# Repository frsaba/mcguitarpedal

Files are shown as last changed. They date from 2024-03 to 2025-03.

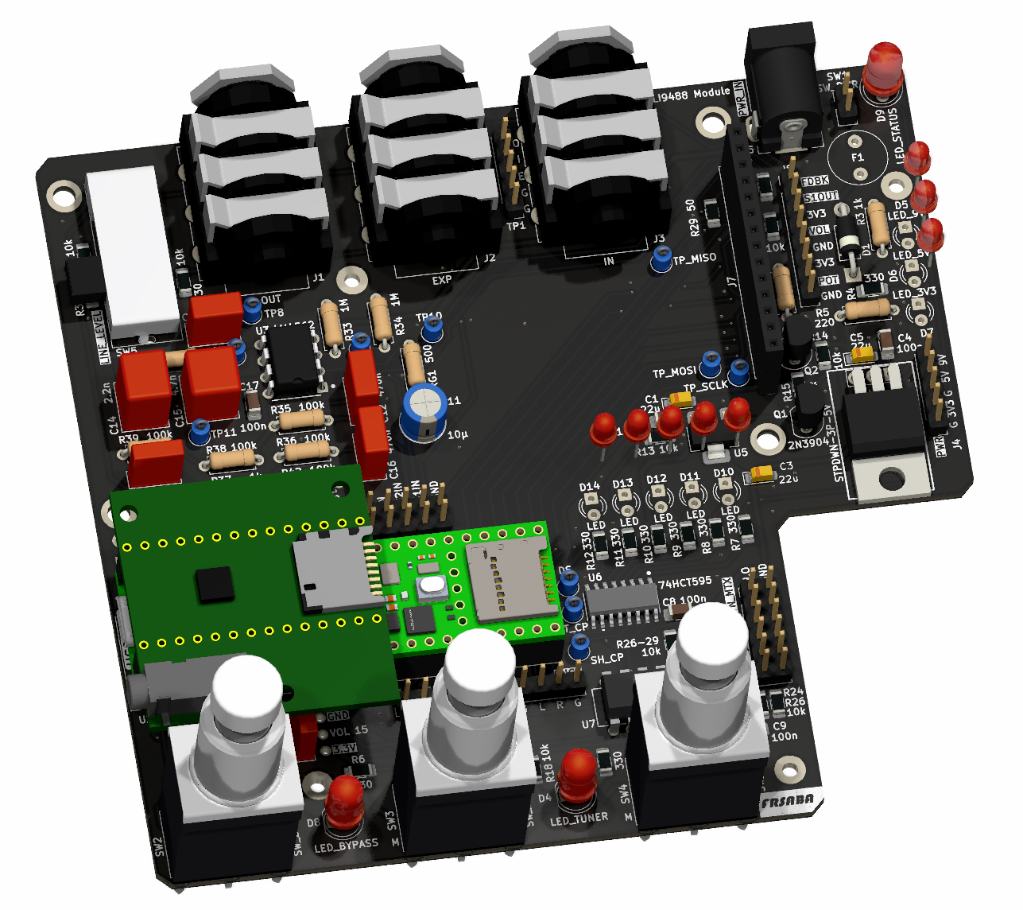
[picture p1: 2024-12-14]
pcb/pcb_3d.png

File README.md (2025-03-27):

# Teensy 4.1 Guitar Effects Pedal


#### Custom dual-layer PCB design:
- LM4562 based preamplifier stage with adjustable gain (1-20x) and 3-way attenuation switch for line-level compatibility
- 8+2+1 programmable buttons (up to 8 pushbuttons, 2 footswitches, 1 true bypass switch)
- 3 potentiometers (preamp gain + 2 programmable)
- 3 encoders (3 headers, but 2 are in use for now)
- 8 programmable LEDs
- 9V barrel jack input or USB power

[PCB design, front side](https://github.com/user-attachments/files/19494445/pcb_front.pdf)

[PCB design, back side](https://github.com/user-attachments/files/19494519/pcb_back.pdf)

pcb_3d

20241130_164746_cropped

## Hardware
- [Teensy 4.1](https://www.pjrc.com/store/teensy41.html)
- [Teensy Audio Adaptor board](https://www.pjrc.com/store/teensy3_audio.html)
- ILI9488 LCD panel (backlight brightness adjustable with PWM)

## Software


- C++ with PlatformIO
- [Teensy Audio Library](https://github.com/PaulStoffregen/Audio)
- UI made with [LVGL](https://lvgl.io)
- 5 implemented effects (more to come):
  - Chorus
  - Flanger
  - Tremolo
  - Delay
  - Reverb

Each effect can be separately toggled on/off and mixed with the dry/wet parameter. The effect parameters can be adjusted to tune the sound.

#### Misc. features
- Tuner mode
- Adjustable LED and display brightness
- Bypass switch
- Signal level feedback LED
- USB audio device for recording
- Headphone monitor out via Audio Board

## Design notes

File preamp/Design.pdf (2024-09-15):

## Filter Wizard

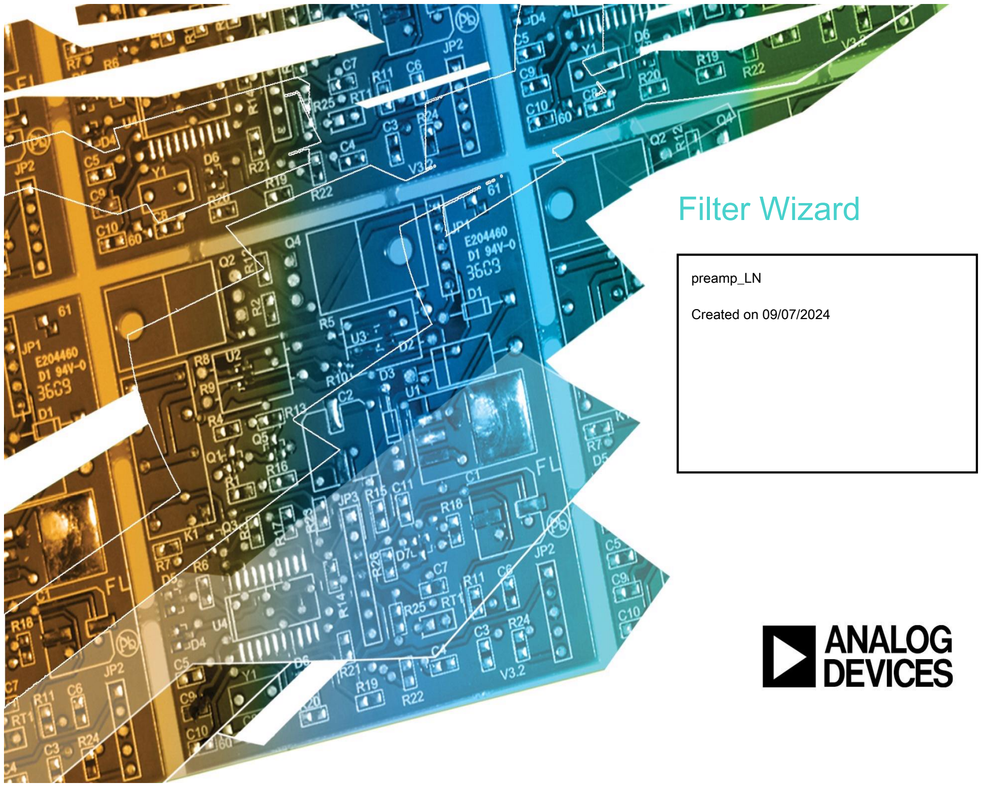
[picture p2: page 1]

preamp_LN

Created on 09/07/2024

## Filter Wizard Design Report

Filter Requirements for Low-Pass, 2nd order Butterworth Specifications: Optimize: Noise; +Vs: 9; -Vs: 0
Gain: 0 dB
Passband: -3dB at 30kHz
Stopband: -20dB at 100kHz
Component Tolerances: Capacitor = 10%; Resistor = 5%; Inductor = 5%; Op Amp GBW = 20% BOM: refer to BOM.csv file

Magnitude(dB)

Magnitude(Volts per Volt)

Phase(degrees)

Phase(radians)

Group Delay

Phase Delay

Step Response

Input Impedance Magnitude

Input Impedance Phase

Noise

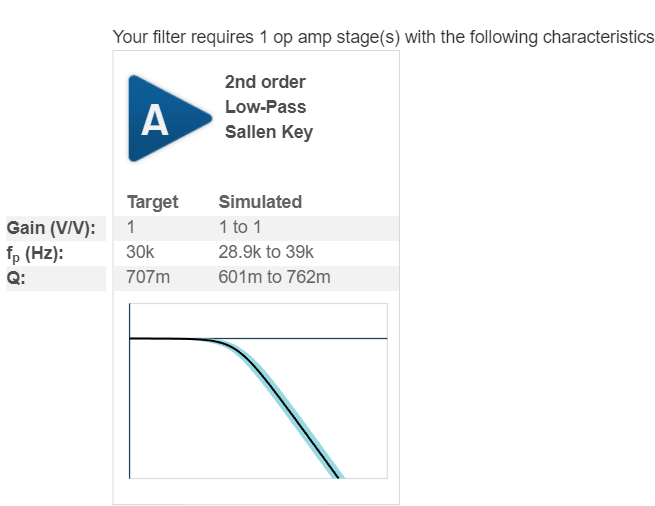
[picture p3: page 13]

Stages

Circuit

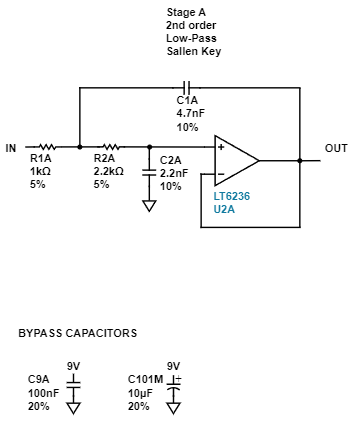
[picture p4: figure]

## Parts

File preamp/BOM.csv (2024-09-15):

Quantity | Reference Designator | Model
1 | R1A | 1.5k ohm, 0603, 5%
1 | R2A | 3.3k ohm, 0603, 5%
3 | R4A, R5M, JP2 | 0 ohm, 0603
1 | C1A | 4.7nF, 0603, C0G, 10%
1 | C2A | 2.2nF, 0603, C0G, 10%
1 | C9A | 100nF, 0603, X7R, 20%
1 | C101M | 10µF, 6032, tantalum, 20%
1 | U1A | ADA4898-1, SOIC EP
4 | J1M, J2M, J3M, J4M | 67996-206HLF, 2x3 0.1" header
3 | J2M, J3M, J4M | 65474-010LF, 0.1" jumper
1 | J1A | BCS-103-L-D-TE, 2x3 0.1" socket
2 | J5M, J6M | 142-0701-851, SMA Jack, board edge female
3 | +VS, -VS, GND | 68000-101HLF, Test pin

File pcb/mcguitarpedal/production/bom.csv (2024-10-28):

Designator | Footprint | Quantity | Value | LCSC Part #
C1, C3, C5, C6 | CP_EIA-3216-18_Kemet-A_Pad1.58x1.35mm_HandSolder | 4 | 22u
C10, C12, C16 | C_Rect_L7.2mm_W3.5mm_P5.00mm_FKS2_FKP2_MKS2_MKP2 | 3 | 470n
C11 | CP_Radial_D6.3mm_P2.50mm | 1 | 10µ
C13 | C_Rect_L7.2mm_W2.5mm_P5.00mm_FKS2_FKP2_MKS2_MKP2 | 1 | 220n
C14 | C_Rect_L7.5mm_W6.5mm_P5.00mm | 1 | 2.2n
C15 | C_Rect_L7.2mm_W7.2mm_P5.00mm_FKS2_FKP2_MKS2_MKP2 | 1 | 4.7n
C17, C2, C4, C8, C9 | 1206 | 5 | 100n
C7 | C_Rect_L7.2mm_W2.5mm_P5.00mm_FKS2_FKP2_MKS2_MKP2 | 1 | 100n
D1, D2, D3 | D_DO-41_SOD81_P10.16mm_Horizontal | 3 | D_Schottky
D10, D11, D12, D13, D14 | LED_D3.0mm | 5 | LED
D4 | LED_D5.0mm | 1 | LED_TUNER
D5 | LED_D3.0mm | 1 | LED_9V
D6 | LED_D3.0mm | 1 | LED_5V
D7 | LED_D3.0mm | 1 | LED_3V3
D8 | LED_D5.0mm | 1 | LED_BYPASS
D9 | LED_D5.0mm | 1 | LED_STATUS
F1 | Fuse_Littelfuse_395Series | 1 | Fuse 1A
J1 | Jack_6.35mm_Neutrik_NMJ6HCD2_Horizontal_3D_MODEL | 1 | OUT
J10 | Encoder_headers | 1 | ENC2
J11 | Encoder_headers | 1 | ENC3
J12 | PinHeader_2x06_P2.54mm_Vertical | 1 | BTN_MTX
J2 | Jack_6.35mm_Neutrik_NMJ6HCD2_Horizontal_3D_MODEL | 1 | EXP
J3 | Jack_6.35mm_Neutrik_NMJ6HCD2_Horizontal_3D_MODEL | 1 | IN
J4 | PinHeader_1x05_P2.54mm_Vertical | 1 | PWR
J5 | BarrelJack_Kycon_KLDX-0202-xC_Horizontal | 1 | PWR_IN
J6 | PREAMP_HEADERS | 1 | PREAMP_HEADERS
J7 | ILI9488 | 1 | ILI9488 Module
J8 | POTS_HEADER | 1 | POT_HP_VOLUME_10k
J9 | Encoder_headers | 1 | ENC1
Q1 | TO-92_Inline | 1 | 2N3904
Q2 | TO-92_Inline | 1 | BC416
R1, RG1 | R_Axial_DIN0207_L6.3mm_D2.5mm_P7.62mm_Horizontal | 2 | 500
R10, R11, R12, R16, R2, R4, R6, R7, R8, R9 | 1206 | 10 | 330
R13, R14, R15, R18, R19, R20, R21, R22, R23, R24, R25, R26, R30, R31, R32 | 1206 | 15 | 10k
R17 | R_Axial_DIN0207_L6.3mm_D2.5mm_P7.62mm_Horizontal | 1 | 100
R27, R28, R29 | 1206 | 3 | 50
R3, R37 | R_Axial_DIN0207_L6.3mm_D2.5mm_P7.62mm_Horizontal | 2 | 1k
R33, R34 | R_Axial_DIN0207_L6.3mm_D2.5mm_P7.62mm_Horizontal | 2 | 1M
R35, R36, R38, R39, R41, R42 | R_Axial_DIN0207_L6.3mm_D2.5mm_P7.62mm_Horizontal | 6 | 100k
R40 | R_Axial_DIN0207_L6.3mm_D2.5mm_P7.62mm_Horizontal | 1 | 2.2k
R5 | R_Axial_DIN0207_L6.3mm_D2.5mm_P7.62mm_Horizontal | 1 | 220
SW1 | PinHeader_1x02_P2.54mm_Vertical | 1 | SW_PWR
SW2 | SW_PUSH_DPDT | 1 | SW_BYPASS
SW3 | SW_PUSH_DPDT | 1 | SW_TUNER
SW4 | SW_PUSH_DPDT | 1 | SW_PRESET
SW5 | DP3T slide switch | 1 | LINE_LEVEL
TP1 | PinHeader_1x05_P2.54mm_Vertical | 1 | TP_SIGNAL
TP10, TP11, TP12, TP8, TP9 | TestPoint_Loop_D1.80mm_Drill1.0mm_Beaded | 5 | TestPoint
TP2 | TestPoint_Loop_D1.80mm_Drill1.0mm_Beaded | 1 | SHIFT_CLK
TP3 | TestPoint_Loop_D1.80mm_Drill1.0mm_Beaded | 1 | TP_LED_DATA
TP4 | TestPoint_Loop_D1.80mm_Drill1.0mm_Beaded | 1 | TP_STORE_CLK
TP5 | TestPoint_Loop_D1.80mm_Drill1.0mm_Beaded | 1 | TP_MOSI
TP6 | TestPoint_Loop_D1.80mm_Drill1.0mm_Beaded | 1 | TP_SCLK
TP7 | TestPoint_Loop_D1.80mm_Drill1.0mm_Beaded | 1 | TP_MISO
U1 | Teensy 4.1 with audio board | 1 | Teensy4.1
U2 | 4.0audioshield | 1 | Teensy Audio Board
U3 | lm4562 | 1 | LM4562
U4 | STPDWN-3P-5V | 1 | STPDWN-3P-5V
U5 | SOT-223-3_TabPin2 | 1 | AMS1117-3.3
U6 | SOT109-1_NEX | 1 | 74HCT595
U7 | DIP16_300_TEX | 1 | 74HC148

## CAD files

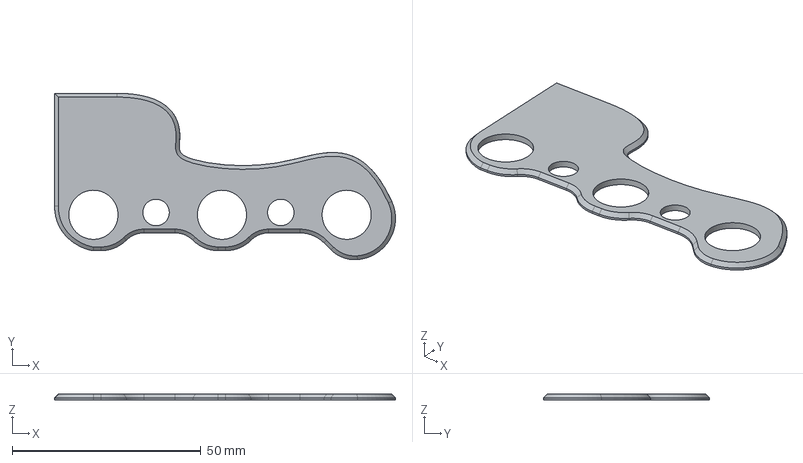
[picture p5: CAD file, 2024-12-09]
mechanical/frontplate/front_cover.step
90.2 x 44.0 x 1.50 mm

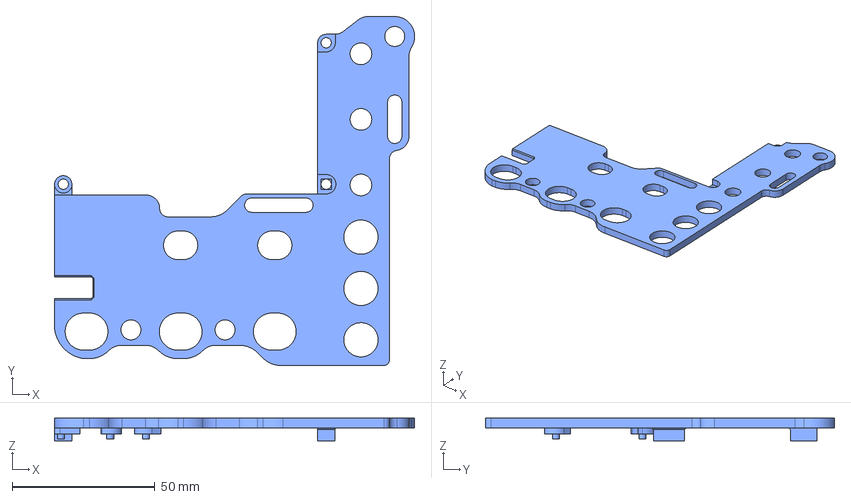
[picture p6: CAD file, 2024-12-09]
mechanical/frontplate/encoder_shroud_4.step
126.4 x 122.4 x 7.90 mm

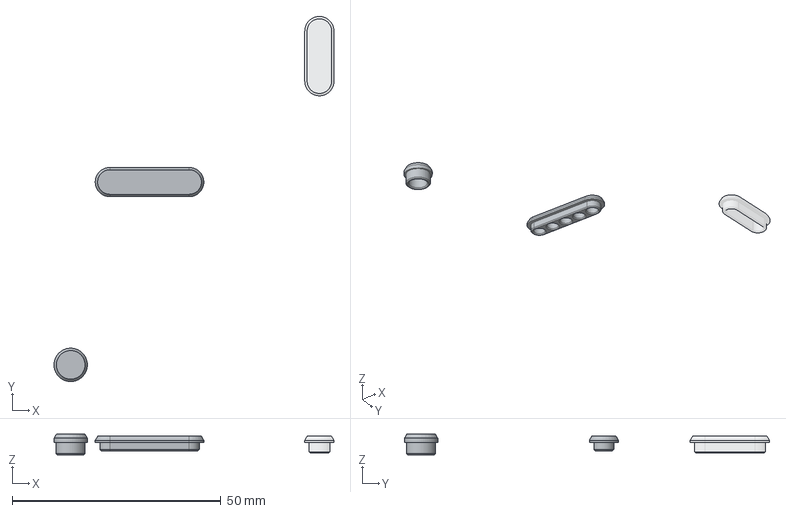
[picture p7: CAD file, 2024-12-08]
mechanical/frontplate/led_covers.step
67.0 x 87.4 x 5.00 mm
LED_cover_3x3mm_slot
LED_cover_1x5mm
LED_cover_5x3mm_holes

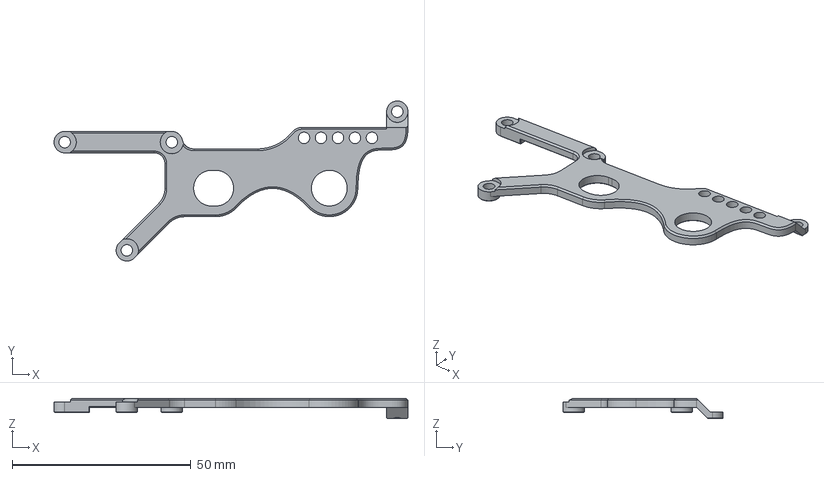
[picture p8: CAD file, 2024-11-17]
mechanical/frontplate/encoder-shroud.step
99.2 x 44.8 x 5.70 mm

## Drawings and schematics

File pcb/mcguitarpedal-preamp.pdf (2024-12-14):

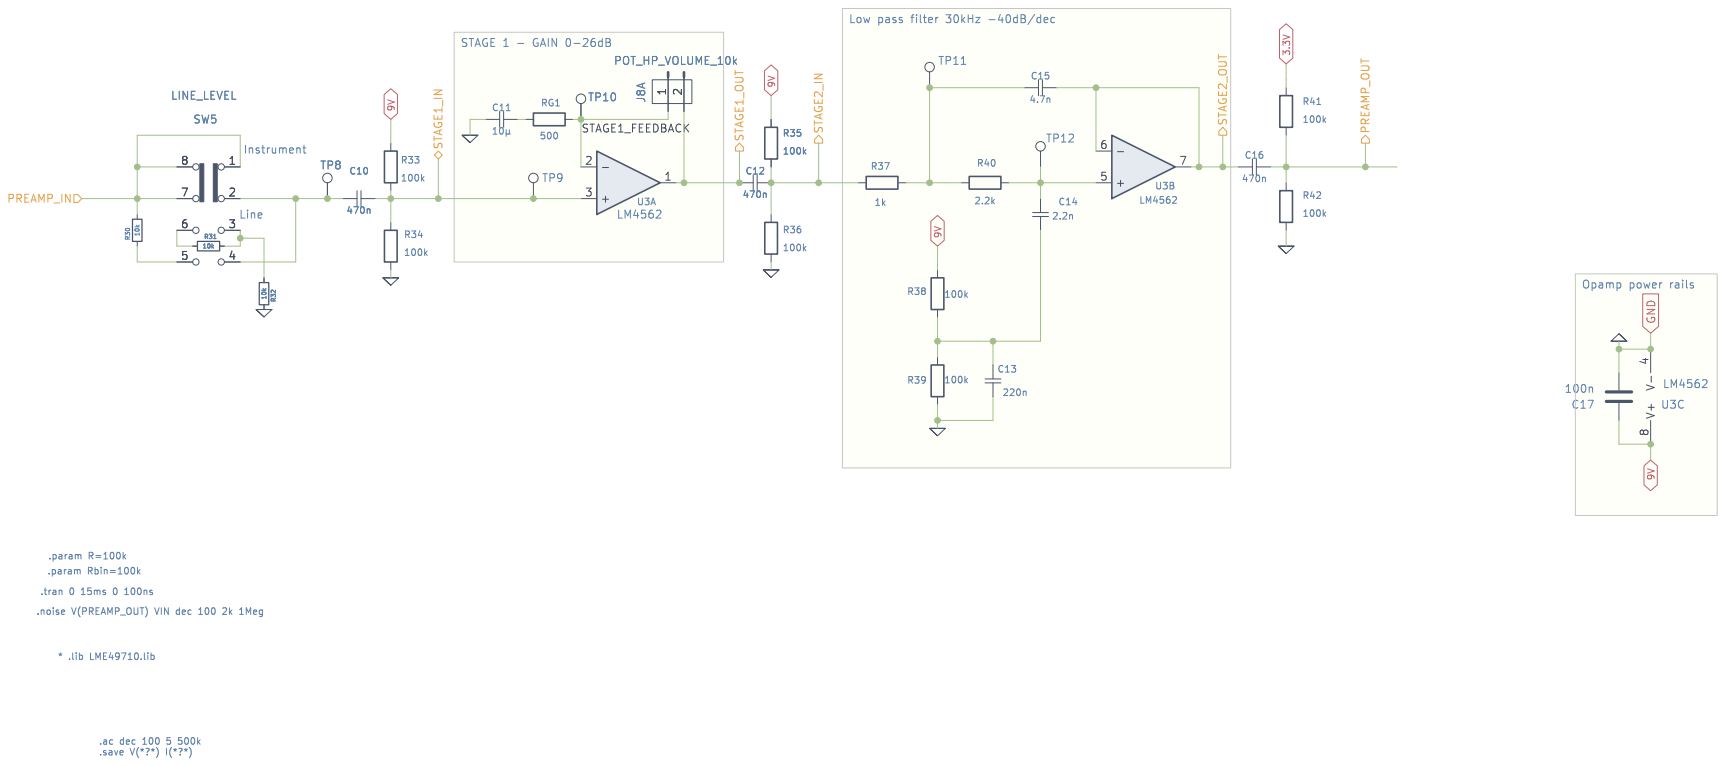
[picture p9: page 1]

Low pass filter 30kHz -40dB/dec C12

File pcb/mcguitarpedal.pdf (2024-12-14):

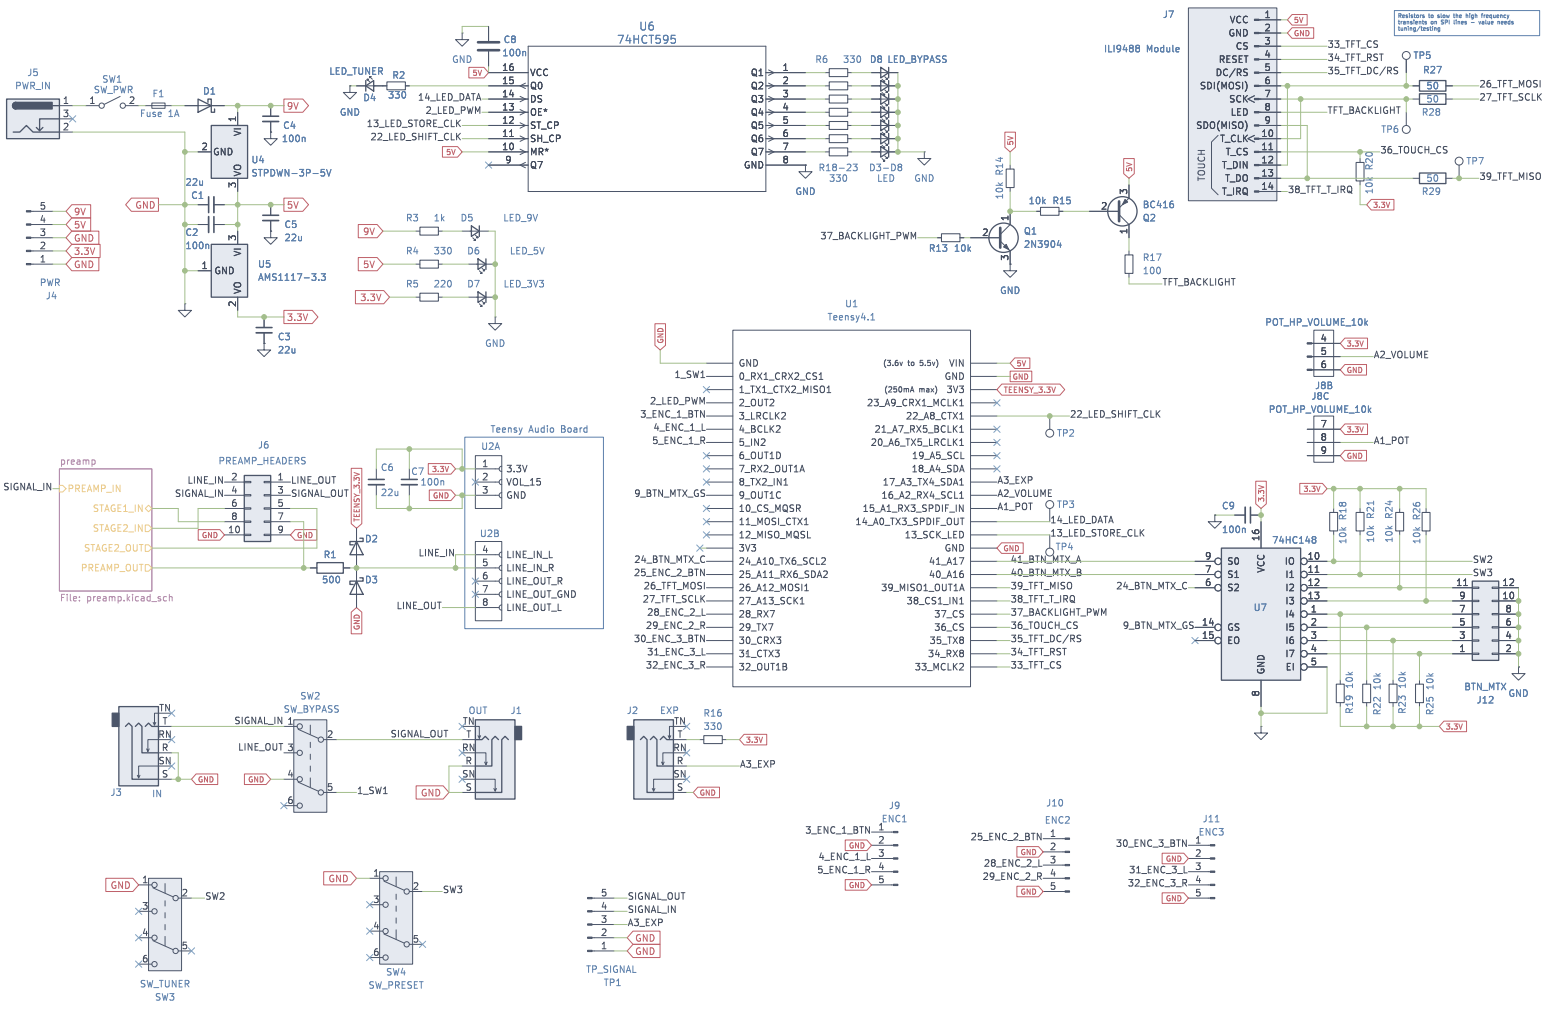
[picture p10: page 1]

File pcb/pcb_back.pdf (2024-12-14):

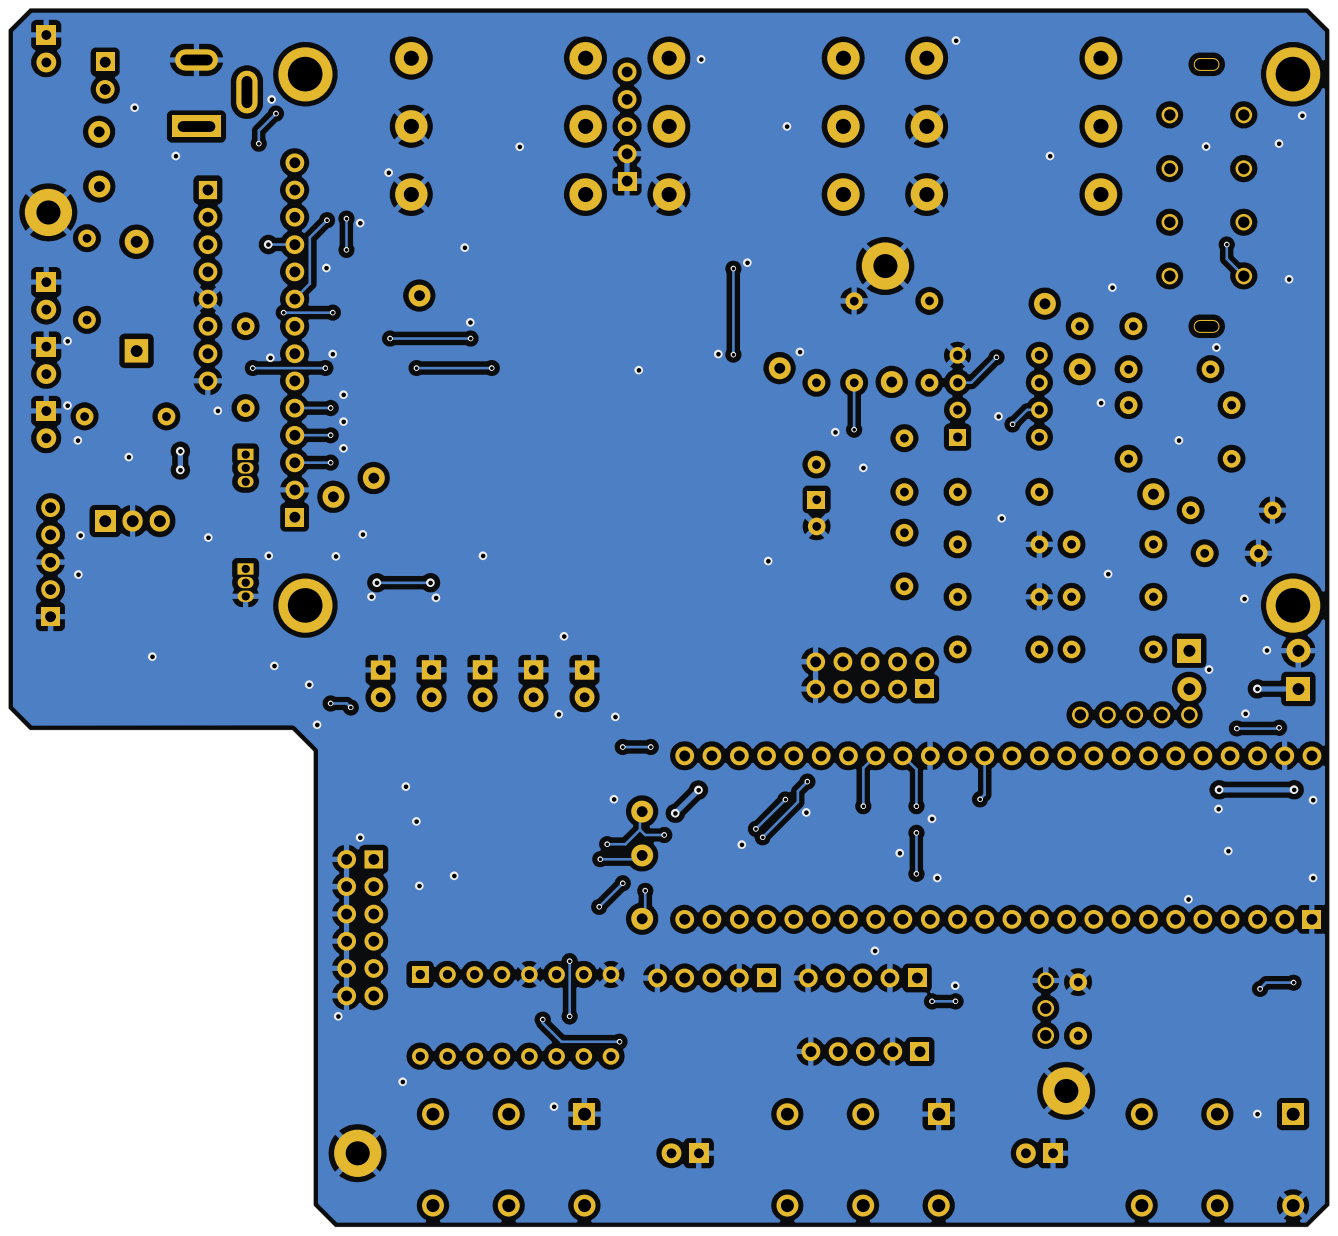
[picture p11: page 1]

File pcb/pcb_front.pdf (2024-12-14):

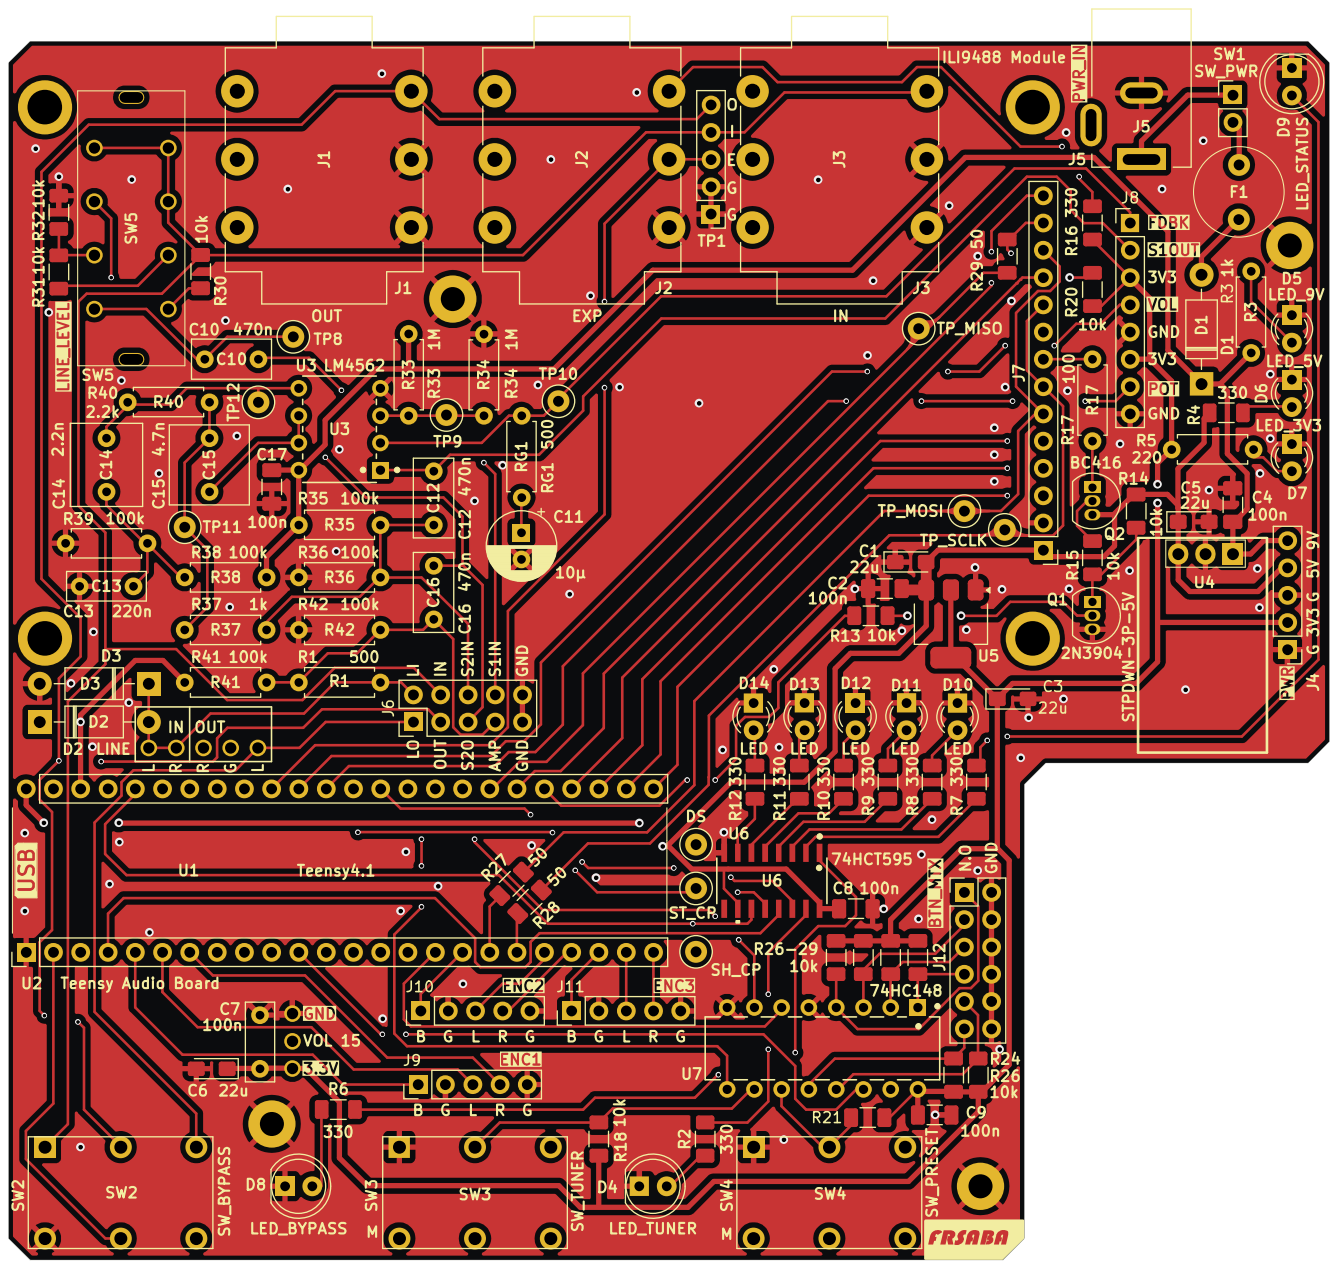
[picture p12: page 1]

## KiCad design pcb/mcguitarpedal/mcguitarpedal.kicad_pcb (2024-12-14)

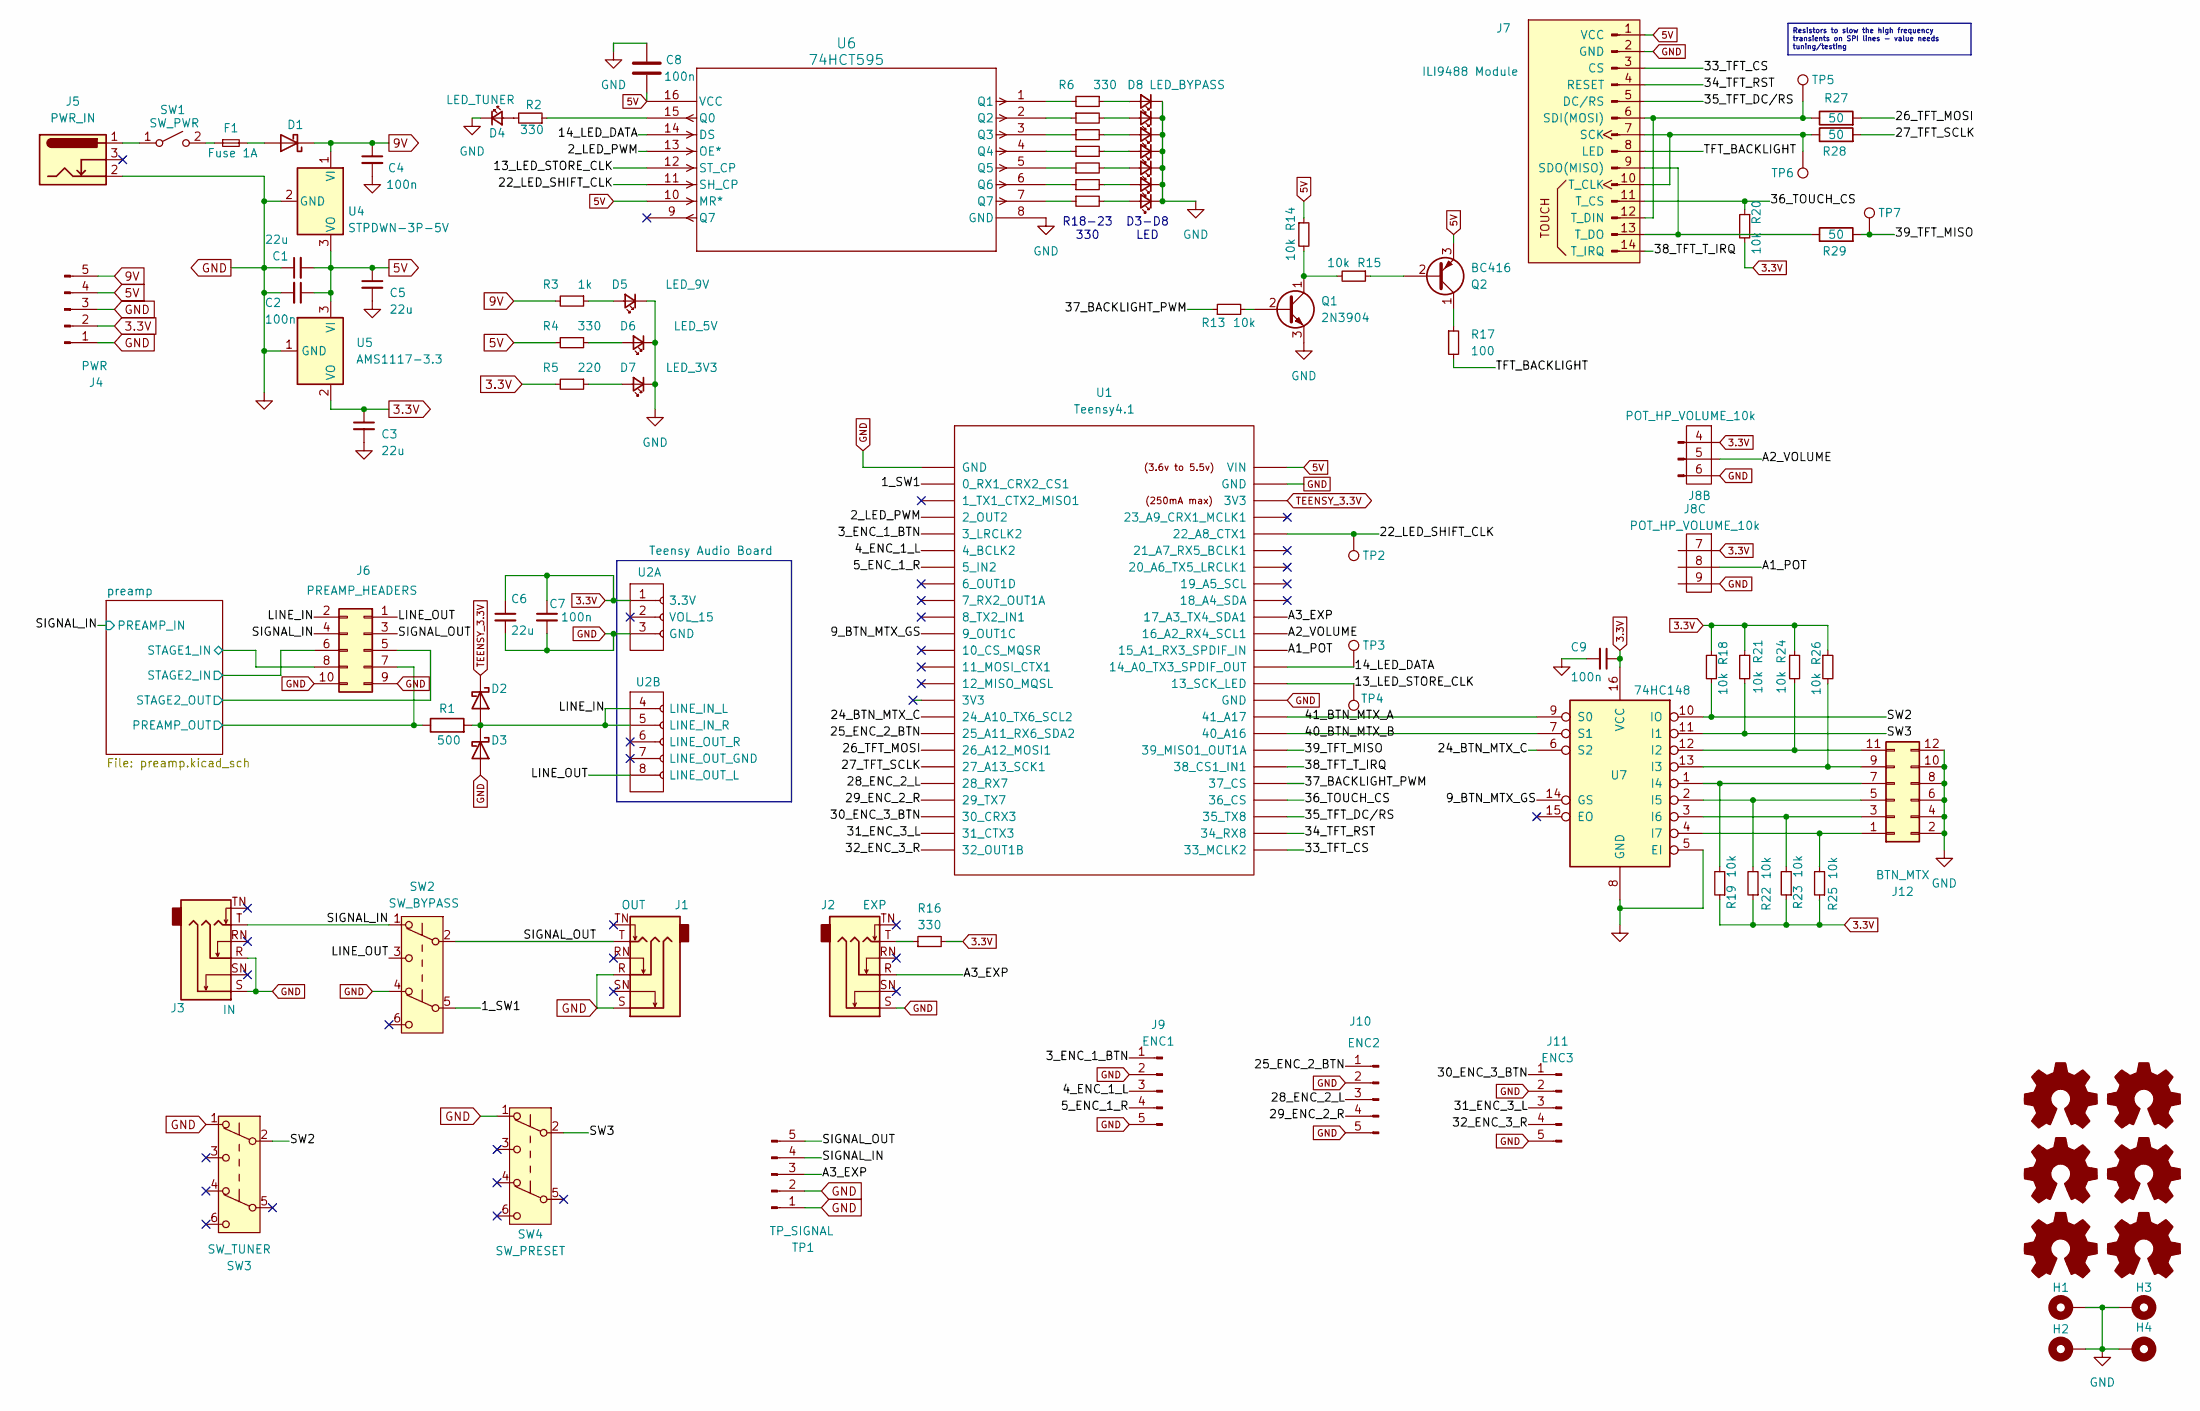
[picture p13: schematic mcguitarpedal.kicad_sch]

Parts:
C1, C3, C5, C6: 22u; CP_EIA-3216-18_Kemet-A_Pad1.58x1.35mm_HandSolder
C2, C4, C8, C9: 100n; C_1206_3216Metric_Pad1.33x1.80mm_HandSolder
C7: 100n; C_Rect_L7.2mm_W2.5mm_P5.00mm_FKS2_FKP2_MKS2_MKP2
D1, D2, D3: D_Schottky; D_DO-41_SOD81_P10.16mm_Horizontal
D4: LED_TUNER; LED_D5.0mm
D5: LED_9V; LED_D3.0mm
D6: LED_5V; LED_D3.0mm
D7: LED_3V3; LED_D3.0mm
D8: LED_BYPASS; LED_D5.0mm
D9: LED_STATUS; LED_D5.0mm
D10, D11, D12, D13, D14: LED; LED_D3.0mm
ENC1, ENC2, ENC3: Logo_Open_Hardware_Small; Floating Encoder
F1: Fuse 1A; Fuse_Littelfuse_395Series
H1, H2, H3, H4: MountingHole_Pad; MountingHole_2.2mm_M2_Pad
J1: OUT; Jack_6.35mm_Neutrik_NMJ6HCD2_Horizontal_3D_MODEL
J2: EXP; Jack_6.35mm_Neutrik_NMJ6HCD2_Horizontal_3D_MODEL
J3: IN; Jack_6.35mm_Neutrik_NMJ6HCD2_Horizontal_3D_MODEL
J4: PWR; PinHeader_1x05_P2.54mm_Vertical
J5: PWR_IN; BarrelJack_Kycon_KLDX-0202-xC_Horizontal
J6: PREAMP_HEADERS
J7: ILI9488 Module; ILI9488
J8: POT_HP_VOLUME_10k; POTS_HEADER
J9: ENC1; Encoder_headers
J10: ENC2; Encoder_headers
J11: ENC3; Encoder_headers
J12: BTN_MTX; PinHeader_2x06_P2.54mm_Vertical
POT1, POT2, POT3: Logo_Open_Hardware_Small; Floating Potentiometer
Q1: 2N3904; TO-92_Inline
Q2: BC416; TO-92_Inline
R1: 500; R_Axial_DIN0207_L6.3mm_D2.5mm_P7.62mm_Horizontal
R2, R4, R6, R7, R8, R9, R10, R11, R12, R16: 330; R_1206_3216Metric_Pad1.30x1.75mm_HandSolder
R3: 1k; R_Axial_DIN0207_L6.3mm_D2.5mm_P7.62mm_Horizontal
R5: 220; R_Axial_DIN0207_L6.3mm_D2.5mm_P7.62mm_Horizontal
R13, R14, R15, R18, R19, R20, R21, R22, R23, R24, R25, R26: 10k; R_1206_3216Metric_Pad1.30x1.75mm_HandSolder
R17: 100; R_Axial_DIN0207_L6.3mm_D2.5mm_P7.62mm_Horizontal
R27, R28, R29: 50; R_1206_3216Metric_Pad1.30x1.75mm_HandSolder
SW1: SW_PWR; PinHeader_1x02_P2.54mm_Vertical
SW2: SW_BYPASS; SW_PUSH_DPDT
SW3: SW_TUNER; SW_PUSH_DPDT
SW4: SW_PRESET; SW_PUSH_DPDT
TP1: TP_SIGNAL; PinHeader_1x05_P2.54mm_Vertical
TP2: SHIFT_CLK; TestPoint_Loop_D1.80mm_Drill1.0mm_Beaded
TP3: TP_LED_DATA; TestPoint_Loop_D1.80mm_Drill1.0mm_Beaded
TP4: TP_STORE_CLK; TestPoint_Loop_D1.80mm_Drill1.0mm_Beaded
TP5: TP_MOSI; TestPoint_Loop_D1.80mm_Drill1.0mm_Beaded
TP6: TP_SCLK; TestPoint_Loop_D1.80mm_Drill1.0mm_Beaded
TP7: TP_MISO; TestPoint_Loop_D1.80mm_Drill1.0mm_Beaded
U1: Teensy4.1; Teensy 4.1 with audio board
U2: Teensy Audio Board; 4.0audioshield
U4: STPDWN-3P-5V
U5: AMS1117-3.3; SOT-223-3_TabPin2
U6: 74HCT595; SOT109-1_NEX
U7: 74HC148; DIP16_300_TEX

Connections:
3.3V: C3.1, C6.1, C7.1, C9.1, J4.2, J8.4, J8.7, R5.2, R16.2, R18.1, R19.1, R20.2, R21.1, R22.1, R23.1, R24.1, R25.1, R26.1, U2.1 (3.3V), U5.2 (VO), U7.16 (VCC)
5V: C1.2, C2.1, C5.1, C8.2, J4.4, J7.1 (VCC), Q2.3 (E), R4.2, R14.1, U1.48 (VIN), U4.3 (VO), U5.3 (VI), U6.10 (MR*), U6.16 (VCC)
9V: C4.1, D1.1 (K), J4.5, R3.2, U4.1 (VI); also elsewhere on the board
/1_SW1: SW2.5 (B), U1.2 (0_RX1_CRX2_CS1)
/2_LED_PWM: U1.4 (2_OUT2), U6.13 (OE*)
/3_ENC_1_BTN: J9.1, U1.5 (3_LRCLK2)
/4_ENC_1_L: J9.3, U1.6 (4_BCLK2)
/5_ENC_1_R: J9.4, U1.7 (5_IN2)
/9_BTN_MTX_GS: U1.11 (9_OUT1C), U7.14 (GS)
/13_LED_STORE_CLK: TP4.1, U1.35 (13_SCK_LED), U6.12 (ST_CP)
/14_LED_DATA: TP3.1, U1.36 (14_A0_TX3_SPDIF_OUT), U6.14 (DS)
/22_LED_SHIFT_CLK: TP2.1, U1.44 (22_A8_CTX1), U6.11 (SH_CP)
/24_BTN_MTX_C: U1.16 (24_A10_TX6_SCL2), U7.6 (S2)
/25_ENC_2_BTN: J10.1, U1.17 (25_A11_RX6_SDA2)
/26_TFT_MOSI: R27.2, U1.18 (26_A12_MOSI1)
/27_TFT_SCLK: R28.2, U1.19 (27_A13_SCK1)
/28_ENC_2_L: J10.3, U1.20 (28_RX7)
/29_ENC_2_R: J10.4, U1.21 (29_TX7)
/30_ENC_3_BTN: J11.1, U1.22 (30_CRX3)
/31_ENC_3_L: J11.3, U1.23 (31_CTX3)
/32_ENC_3_R: J11.4, U1.24 (32_OUT1B)
/33_TFT_CS: J7.3 (CS), U1.25 (33_MCLK2)
/34_TFT_RST: J7.4 (RESET), U1.26 (34_RX8)
/35_TFT_DC/RS: J7.5 (DC/RS), U1.27 (35_TX8)
/36_TOUCH_CS: J7.11 (T_CS), R20.1, U1.28 (36_CS)
/37_BACKLIGHT_PWM: R13.1, U1.29 (37_CS)
/38_TFT_T_IRQ: J7.14 (T_IRQ), U1.30 (38_CS1_IN1)
/39_TFT_MISO: R29.2, TP7.1, U1.31 (39_MISO1_OUT1A)
/40_BTN_MTX_B: U1.32 (40_A16), U7.7 (S1)
/41_BTN_MTX_A: U1.33 (41_A17), U7.9 (S0)
/A1_POT: J8.8, U1.37 (15_A1_RX3_SPDIF_IN)
/A2_VOLUME: J8.5, U1.38 (16_A2_RX4_SCL1)
/A3_EXP: J2.R, TP1.3, U1.39 (17_A3_TX4_SDA1)
/LINE_IN: D2.2 (A), D3.1 (K), J6.2, R1.2, U2.4 (LINE_IN_L), U2.5 (LINE_IN_R)
/LINE_OUT: J6.1, SW2.3 (C), U2.8 (LINE_OUT_L)
/SIGNAL_IN: J3.T, J6.4, SW2.1 (A), TP1.4; also elsewhere on the board
/SIGNAL_OUT: J1.T, J6.3, SW2.2 (B), TP1.5
/SW2: R18.2, SW3.2 (B), U7.10 (IO)
/SW3: R21.2, SW4.2 (B), U7.11 (I1)
/TFT_BACKLIGHT: J7.8 (LED), R17.2
/preamp/PREAMP_OUT: J6.7, R1.1; also elsewhere on the board
/preamp/STAGE1_IN: J6.8; also elsewhere on the board
/preamp/STAGE2_IN: J6.6; also elsewhere on the board
/preamp/STAGE2_OUT: J6.5; also elsewhere on the board
GND: C1.1, C2.2, C3.2, C4.2, C5.2, C6.2, C7.2, C8.1, C9.2, D3.2 (A), D4.1 (K), D5.1 (K), D6.1 (K), D7.1 (K), D8.1 (K), D9.1 (K), D10.1 (K), D11.1 (K), D12.1 (K), D13.1 (K), D14.1 (K), H1.1, H2.1, H3.1, H4.1, J1.R, J1.S, J2.S, J3.R, J3.S, J4.1, J4.3, J5.2, J6.9, J6.10, J7.2 (GND), J8.6, J8.9, J9.2, J9.5, J10.2, J10.5, J11.2, J11.5, J12.2, J12.4, J12.6, J12.8, J12.10, J12.12, Q1.3 (E), SW2.4 (A), SW3.1 (A), SW4.1 (A), TP1.1, TP1.2, U1.1 (GND), U1.34 (GND), U1.47 (GND), U2.3 (GND), U4.2 (GND), U5.1 (GND), U6.8 (GND), U7.5 (EI), U7.8 (GND); also elsewhere on the board
unnamed: D1.2 (A), F1.2
unnamed: D4.2 (A), R2.2
unnamed: D5.2 (A), R3.1
unnamed: D6.2 (A), R4.1
unnamed: D7.2 (A), R5.1
unnamed: D8.2 (A), R6.1
unnamed: D9.2 (A), R7.2
unnamed: D10.2 (A), R8.2
unnamed: D11.2 (A), R9.2
unnamed: D12.2 (A), R10.2
unnamed: D13.2 (A), R11.2
unnamed: D14.2 (A), R12.2
unnamed: J2.T, R16.1
unnamed: J7.7 (SCK), J7.10 (T_CLK), R28.1, TP6.1
unnamed: J7.6 (SDI(MOSI)), J7.12 (T_DIN), R27.1, TP5.1
unnamed: J7.9 (SDO(MISO)), J7.13 (T_DO), R29.1
unnamed: J12.1, R25.2, U7.4 (I7)
unnamed: J12.3, R23.2, U7.3 (I6)
unnamed: J12.5, R22.2, U7.2 (I5)
unnamed: J12.7, R19.2, U7.1 (I4)
unnamed: J12.9, R26.2, U7.13 (I3)
unnamed: J12.11, R24.2, U7.12 (I2)
unnamed: Q1.2 (B), R13.2
unnamed: Q1.1 (C), R14.2, R15.2
unnamed: Q2.2 (B), R15.1
unnamed: Q2.1 (C), R17.1
unnamed: R12.1, U6.7 (Q7)
unnamed: J5.1, SW1.1 (A)
unnamed: F1.1, SW1.2 (B)
unnamed: R2.1, U6.15 (Q0)
unnamed: R6.2, U6.1 (Q1)
unnamed: R7.1, U6.2 (Q2)
unnamed: R8.1, U6.3 (Q3)
unnamed: R9.1, U6.4 (Q4)
unnamed: R10.1, U6.5 (Q5)
unnamed: R11.1, U6.6 (Q6)
TEENSY_3.3V: D2.1 (K), U1.46 (3V3); also elsewhere on the board

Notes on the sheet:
Resistors to slow the high frequency transients on SPI lines - value needs tuning/testing
D3-D8 LED
R18-23 330

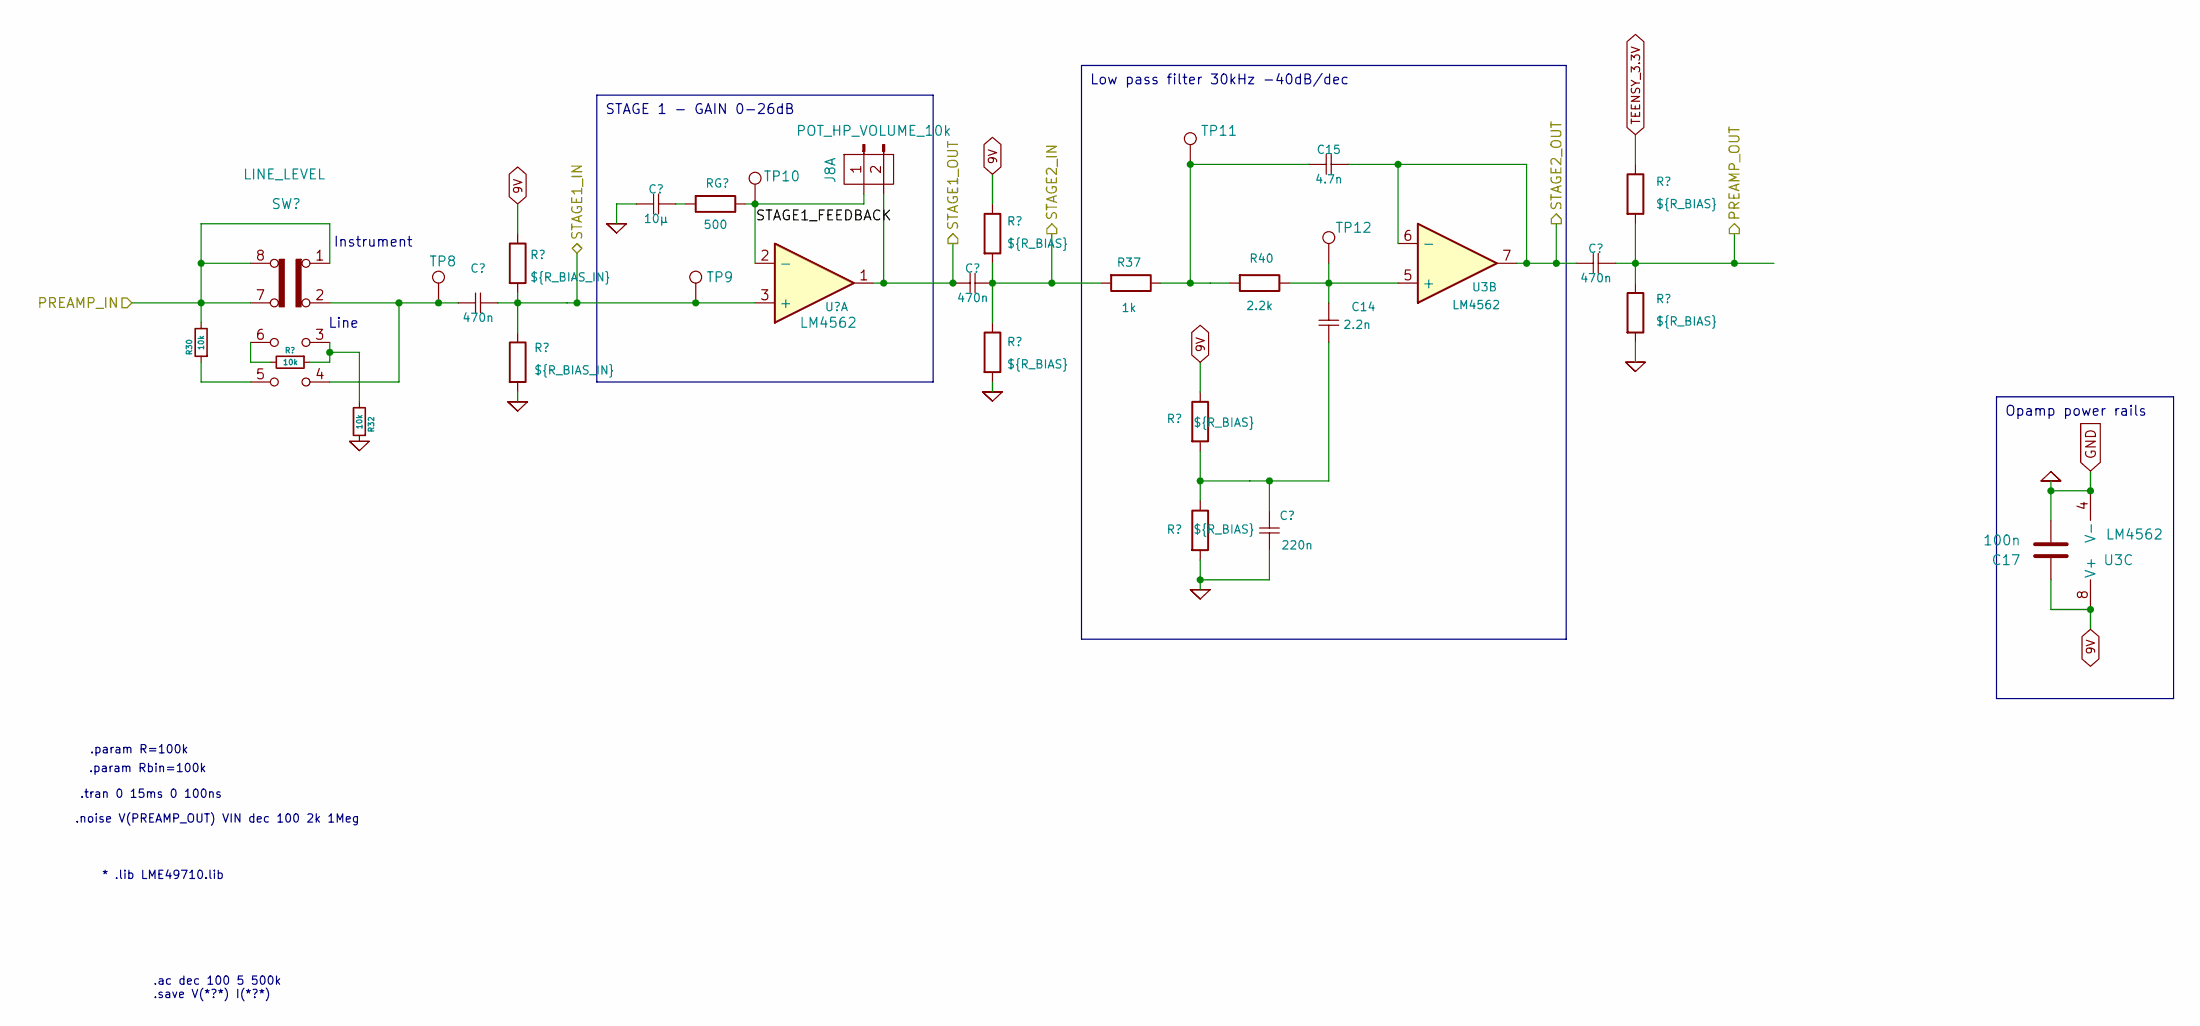
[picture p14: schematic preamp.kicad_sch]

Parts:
C10, C12, C16: 470n; C_Rect_L7.2mm_W3.5mm_P5.00mm_FKS2_FKP2_MKS2_MKP2
C11: 10µ; CP_Radial_D6.3mm_P2.50mm
C13: 220n; C_Rect_L7.2mm_W2.5mm_P5.00mm_FKS2_FKP2_MKS2_MKP2
C14: 2.2n; C_Rect_L7.5mm_W6.5mm_P5.00mm
C15: 4.7n; C_Rect_L7.2mm_W7.2mm_P5.00mm_FKS2_FKP2_MKS2_MKP2
C17: 100n; C_1206_3216Metric_Pad1.33x1.80mm_HandSolder
J8: POT_HP_VOLUME_10k; POTS_HEADER
R30, R31, R32: 10k; R_1206_3216Metric_Pad1.30x1.75mm_HandSolder
R33, R34: ${R_BIAS_IN}; R_Axial_DIN0207_L6.3mm_D2.5mm_P7.62mm_Horizontal
R35, R36, R38, R39, R41, R42: ${R_BIAS}; R_Axial_DIN0207_L6.3mm_D2.5mm_P7.62mm_Horizontal
R37: 1k; R_Axial_DIN0207_L6.3mm_D2.5mm_P7.62mm_Horizontal
R40: 2.2k; R_Axial_DIN0207_L6.3mm_D2.5mm_P7.62mm_Horizontal
RG1: 500; R_Axial_DIN0207_L6.3mm_D2.5mm_P7.62mm_Horizontal
SW5: LINE_LEVEL; DP3T slide switch
TP8, TP9, TP10, TP11, TP12: TestPoint; TestPoint_Loop_D1.80mm_Drill1.0mm_Beaded
U3: LM4562; lm4562

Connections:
9V: C17.1, R33.1, R35.1, R38.1, U3.8 (V+); also elsewhere on the board
/SIGNAL_IN: R30.2, SW5.1 (A), SW5.7 (B), SW5.8 (C); also elsewhere on the board
/preamp/PREAMP_OUT: C16.1, R41.2, R42.1; also elsewhere on the board
/preamp/STAGE1_FEEDBACK: J8.1, RG1.1, TP10.1, U3.2 (-)
/preamp/STAGE1_IN: C10.1, R33.2, R34.1, TP9.1, U3.3 (+); also elsewhere on the board
/preamp/STAGE1_OUT: C12.2, J8.2, U3.1
/preamp/STAGE2_IN: C12.1, R35.2, R36.1, R37.2; also elsewhere on the board
/preamp/STAGE2_OUT: C15.1, C16.2, U3.6 (-), U3.7; also elsewhere on the board
GND: C11.2, C13.2, C17.2, R32.1, R34.2, R36.2, R39.2, R42.2, U3.4 (V-); also elsewhere on the board
unnamed: C11.1, RG1.2
unnamed: C13.1, C14.2, R38.2, R39.1
unnamed: C15.2, R37.1, R40.2, TP11.1
unnamed: R30.1, SW5.5
unnamed: R31.1, R32.2, SW5.3 (C)
unnamed: R31.2, SW5.6 (A)
unnamed: C10.2, SW5.2 (B), SW5.4 (D), TP8.1
unnamed: C14.1, R40.1, TP12.1, U3.5 (+)
TEENSY_3.3V: R41.1; also elsewhere on the board

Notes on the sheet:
Opamp power rails
Low pass filter 30kHz -40dB/dec
STAGE 1 - GAIN 0-26dB
Line
Instrument
.param R=100k
.noise V(PREAMP_OUT) VIN dec 100 2k 1Meg
.param Rbin=100k
* .lib LME49710.lib
.ac dec 100 5 500k .save V(*?*) I(*?*)
.tran 0 15ms 0 100ns

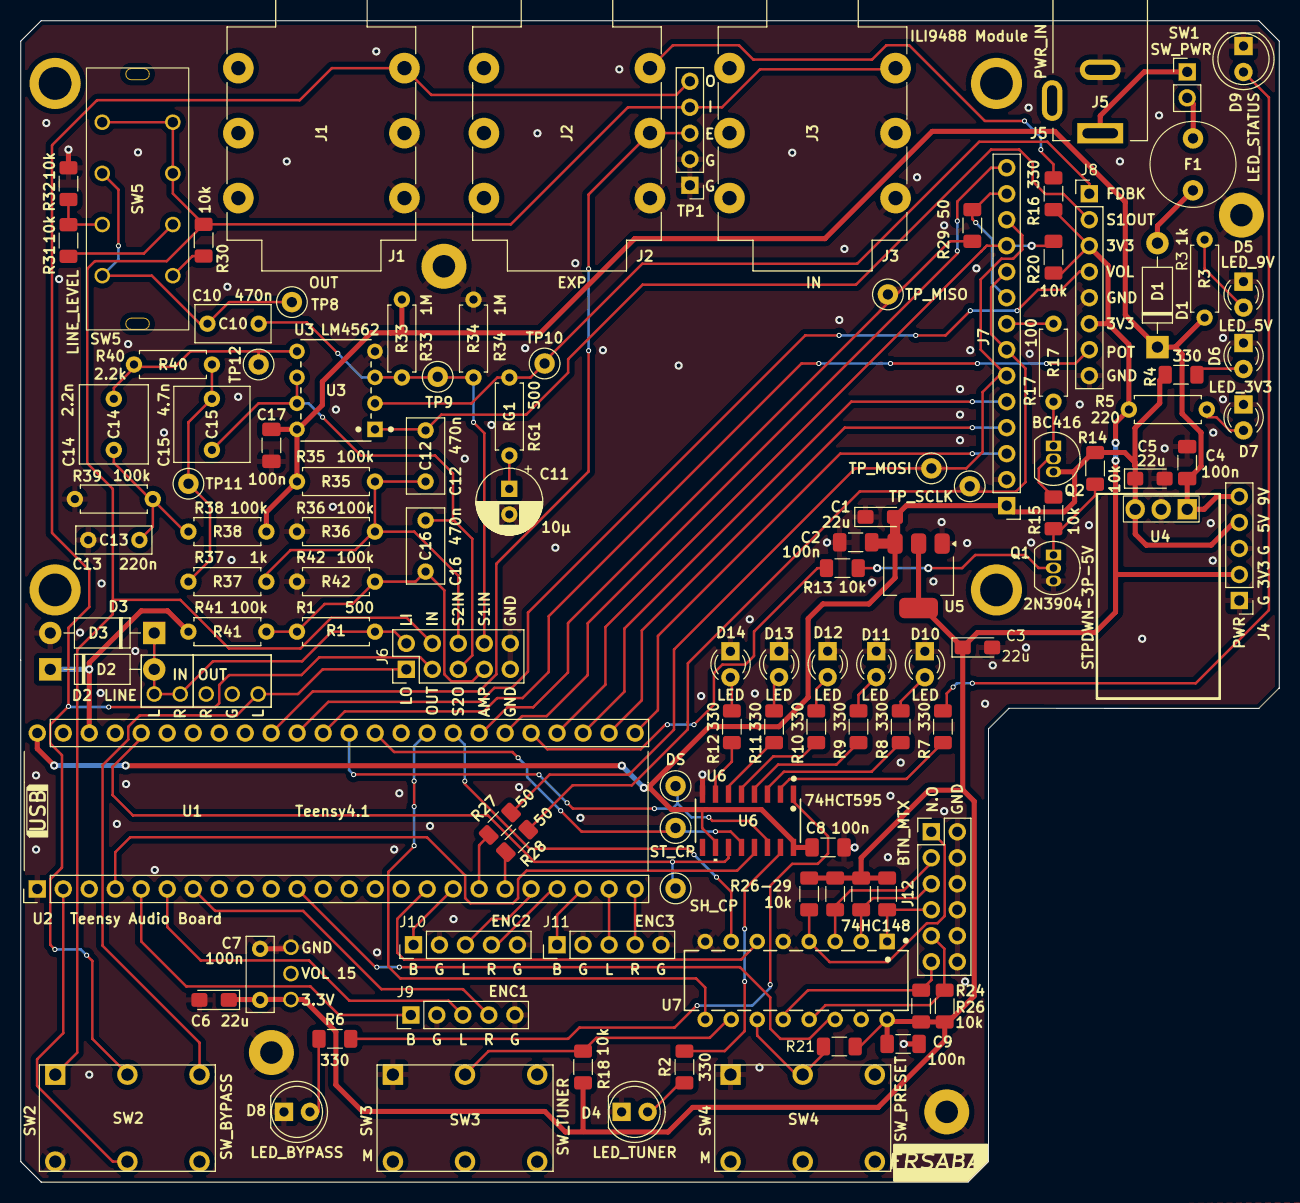
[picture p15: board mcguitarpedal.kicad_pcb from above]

Board: 2 copper layers, 123.0 x 113.5 mm, 123 parts (0 on the bottom side), 92 nets.

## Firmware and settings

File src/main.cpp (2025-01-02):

#include <Arduino.h>
#include <Encoder.h>
#include <Audio.h>
#include "SPI.h"
#include <TFT_eSPI.h> 
#include "OneButton.h"

#include <effects/delay.cpp>
#include <effects/reverb.cpp>
#include <effects/tremolo.cpp>
#include <effects/chorus.cpp>
#include <effects/flanger.cpp>
#include <interface/display.h>
#include <lvgl.h>
#define TFT_RGB_ORDER TFT_BGR
#include <presets/presets.h>
#include "interface/led_driver.h"
#include <interface/button_decoder.h>
#include "interface/tuner.h"
#include <usb_audio.h>

#define MASTER_POT A1
#define HP_VOLUME_POT A2
#define EXP A3
#define BACKLIGHT_PWM 37
#define SW_BYPASS 0
#define PWM_FREQ 100000

#define MAX_VOLUME 0.7

#define CHAIN_LENGTH 5
Effect *effects_chain[] = {new Chorus(), new Tremolo(), new Flanger(), new Delay(), new Reverb()};
Effect *chorus_effect = effects_chain[0];
Effect *tremolo_effect = effects_chain[1];
Effect *delay_effect = effects_chain[2];
Effect *reverb_effect = effects_chain[3];

#define DRY_CHANNEL 0
#define WET_CHANNEL 1

int selected_effect_index = 0;

AudioInputI2S audio_input;       
AudioMixer4 final_mixer;      
AudioAnalyzeNoteFrequency tuner; 
float tuner_threshold = DEFAULT_TUNER_THRESHOLD;
AudioAnalyzeRMS rms_meter;
float rms_threshold = 0.03;

AudioOutputI2S audio_output;

#ifdef USB_AUDIO
AudioOutputUSB audio_output_usb;
#endif

std::vector<AudioConnection*> patch_cords(8 + CHAIN_LENGTH * 4);

bool tuner_mode = false;
bool debug_mode = false;
bool settings_menu = false;

FLASHMEM void create_audio_connections() {
    // Connect input to the start of the effects chain
    patch_cords.push_back(new AudioConnection(audio_input, effects_chain[0]->input_amp));
    patch_cords.push_back(new AudioConnection(audio_input, 0, final_mixer, DRY_CHANNEL));

    // Connect effects together
    for (size_t i = 0; i < CHAIN_LENGTH; i++) {
        patch_cords.push_back(new AudioConnection(effects_chain[i]->input_amp, 0, effects_chain[i]->dry_wet_mixer, DRY_CHANNEL)); // Dry to dry_wet_mixer
        patch_cords.push_back(new AudioConnection(effects_chain[i]->input_amp, *effects_chain[i]->chain_start));  // Wet in
        patch_cords.push_back(new AudioConnection(*effects_chain[i]->chain_end, 0, effects_chain[i]->dry_wet_mixer, WET_CHANNEL)); // Wet out to dry_wet_mixer

        if (i < CHAIN_LENGTH - 1) {
            patch_cords.push_back(new AudioConnection(effects_chain[i]->dry_wet_mixer, effects_chain[i + 1]->input_amp));
        }
    }

    // Connect last effect to output
    patch_cords.push_back(new AudioConnection(effects_chain[CHAIN_LENGTH - 1]->dry_wet_mixer, 0, final_mixer, WET_CHANNEL));
    patch_cords.push_back(new AudioConnection(final_mixer, 0, audio_output, 0));
    patch_cords.push_back(new AudioConnection(final_mixer, 0, audio_output, 1));

	#ifdef USB_AUDIO
	patch_cords.push_back(new AudioConnection(audio_input, 0, audio_output_usb, 0));
    patch_cords.push_back(new AudioConnection(final_mixer, 0, audio_output_usb, 1));
	#endif

    // Additional connections
    patch_cords.push_back(new AudioConnection(audio_input, tuner));
    patch_cords.push_back(new AudioConnection(audio_input, rms_meter));
}


AudioControlSGTL5000 sgtl5000; // xy=256.1037902832031,460


// OneButton button_1(3, true);
// Encoder encoder_1(4, 5);

OneButton button_2(25, true, true);
Encoder encoder_2(29, 28);

OneButton button_3(30, true, true);
Encoder encoder_3(32, 31);


extern TFT_eSPI tft;


elapsedMillis volmsec = 0;

std::vector<AudioConnection> patchCords;

extern preset_bank_t preset_bank;

FLASHMEM void setup()
{
    analogWriteFrequency(BACKLIGHT_PWM, PWM_FREQ);
    analogWriteFrequency(LED_PWM, PWM_FREQ);

    setup_leds();

	pinMode(MASTER_POT, INPUT);
    pinMode(HP_VOLUME_POT, INPUT);
    pinMode(EXP, INPUT);
    pinMode(SW_BYPASS, INPUT_PULLUP);
	pinMode(BACKLIGHT_PWM, OUTPUT);


	init_display();
    create_status_bar();
	create_effect_lists(effects_chain, CHAIN_LENGTH);
    

    // analogWrite(BACKLIGHT_PWM, 0); //Initalize display pwm early to avoid flicker
    Serial.begin( 115200 );
    AudioMemory(1200);

	//TODO: toggle dry/wet for entire chain
    final_mixer.gain(0, 0);
    final_mixer.gain(1, 1);

	//Initialize preset bank
    preset_bank = {0, NUM_PRESETS, CHAIN_LENGTH, {}};

    //Load active preset
    //TODO: save active preset when it is selected, not just when overwritten
	LV_LOG_USER("Loading saved presets...");
	load_presets_from_eeprom(&preset_bank);


	create_audio_connections();
    sgtl5000.enable();
	sgtl5000.inputSelect(AUDIO_INPUT_LINEIN);
    sgtl5000.volume(0.5);
    sgtl5000.adcHighPassFilterDisable();
	sgtl5000.lineInLevel(0); 
    sgtl5000.lineOutLevel(14);
    

    tuner.begin(DEFAULT_TUNER_THRESHOLD);
    while(!Serial && millis() < 2500){};

	if(Serial)
		Serial.printf("Serial connected in %d\n", millis());

    
    led_set(255, false);
	led_set(LED_BYPASS, !digitalRead(SW_BYPASS));


	LV_LOG_USER("Applying active preset...");
	load_preset(preset_get_active_index());

	digitalWrite(BACKLIGHT_PWM, 1);
	
	setup_decoder();

}

void loop()
{
    static bool blink_state = 0;
    static bool bypass = 0;
    static float prev_volume = -1;
    static float prev_mix = -1;
	static bool prev_bypass = false;

    bypass = !digitalRead(SW_BYPASS);
    if (volmsec > 500)
    {
        // led_toggle(255 - LED_STATUS);
        volmsec = 0;  


        // Serial.println(mix);
		// led_toggle(LED_STATUS);
        // led_set(LED_BYPASS, !digitalRead(SW_BYPASS));

        #ifdef LOG_RAM_USAGE
            Serial.printf("CPU: %f, %f\nMemory: %d, %d\n", AudioProcessorUsage(), AudioProcessorUsageMax(), AudioMemoryUsage(), AudioMemoryUsageMax());
        #endif

        if(bypass)
        {
            blink_state = !blink_state;
            led_set(LED_BYPASS, blink_state);
        }
        else
        {
            blink_state = false;
        }
        digitalWrite(LED_BUILTIN, blink_state);


    }

    // statusbar_log_fmt("Mix %.2f HP: %.2f", 1- mix, volume);

    float volume = analogRead(HP_VOLUME_POT);
    volume = volume / 1023.0;

    if(fabs(volume - prev_volume) > 0.05)
    {
        sgtl5000.volume(volume * MAX_VOLUME);
        statusbar_set_headphone_arc(volume);

        prev_volume = volume;
    }


    float mix = analogRead(MASTER_POT) / 1023.0;
    if(fabs(mix - prev_mix) > 0.05)
    {
        final_mixer.gain(DRY_CHANNEL, mix);
        final_mixer.gain(WET_CHANNEL, 1 - mix);

        statusbar_set_mix_arc(1 - mix);

        prev_mix = mix;
    }

	if(bypass != prev_bypass)
	{
		led_set(LED_BYPASS, bypass);
		prev_bypass = bypass;
	}

    // button_1.tick();
    button_2.tick();
    button_3.tick();

	lv_timer_handler();
    decoder_tick();

    if(rms_meter.available())
    {
        float rms = rms_meter.read();
        // statusbar_log_fmt("RMS: %.3f", rms_meter.read());

        led_set(LED_STATUS, rms > rms_threshold);
    }
    else led_set(LED_STATUS, 0);

    if(tuner_mode)
    {
        tuner_tick();
    }
    delay(25);
}

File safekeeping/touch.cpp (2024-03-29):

#include <Arduino.h>

#include "SPI.h"
#include "ILI9488_t3.h"

#define TFT_RST 34
#define TFT_DC 9
#define TFT_CS 10
#define MOSI 11
#define MISO 12
#define SCLK 13
#define T_CS 33
#define T_IRQ 35

ILI9488_t3 tft = ILI9488_t3(&SPI, TFT_CS, TFT_DC, TFT_RST, MOSI, SCLK, MISO);

#include <XPT2046_Touchscreen.h>
XPT2046_Touchscreen ts(T_CS, T_IRQ); 

void setup() {
  Serial.begin(38400);
  tft.begin();
  tft.setRotation(3);
  tft.fillScreen(ILI9488_BLACK);
  ts.begin();
  ts.setRotation(3);
  while (!Serial && (millis() <= 1000));
}

boolean wastouched = true;

void loop() {
  boolean istouched = ts.touched();
  if (istouched) {
    TS_Point p = ts.getPoint();
    if (!wastouched) {
      tft.fillScreen(ILI9488_BLACK);
      tft.setTextColor(ILI9488_YELLOW);
      tft.setTextSize(3);
      tft.setCursor(60, 80);
      tft.print("Touch");
    }
    tft.fillRect(100, 150, 140, 60, ILI9488_BLACK);
    tft.setTextColor(ILI9488_GREEN);
    tft.setTextSize(1);
    tft.setCursor(100, 150);
    tft.print("X = ");
    tft.print(p.x);
    tft.setCursor(100, 180);
    tft.print("Y = ");
    tft.print(p.y);
    Serial.print(", x = ");
    Serial.print(p.x);
    Serial.print(", y = ");
    Serial.println(p.y);
  } else {
    if (wastouched) {
      tft.fillScreen(ILI9488_BLACK);
      tft.setTextColor(ILI9488_RED);
      tft.setTextSize(2);
      tft.setCursor(120, 50);
      tft.print("No");
      tft.setCursor(80, 120);
      tft.print("Touch");
    }
    Serial.println("no touch");
  }
  wastouched = istouched;
  delay(100);
}

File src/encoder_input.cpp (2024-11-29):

#include <encoder_input.h>


lv_indev_t* preset_selector;
lv_indev_t* param_selector;
lv_indev_t* value_selector;


void set_scroll_callback(lv_indev_t* indev, void(*callback)(int)){
	input_device_data* idd = (input_device_data*)lv_indev_get_user_data(indev);
	idd->encoder_scroll_cb = callback;
}

void encoder_read(lv_indev_t * indev, lv_indev_data_t*data){
	input_device_data* idd = (input_device_data*)lv_indev_get_user_data(indev);
	//Divide by 4 as there are 4 pulses sent for every encoder step
	int encoder_value = (idd->encoder->read() + 2) / 4;
	
	data->enc_diff = encoder_value - idd->prev_encoder_value;

	// Call encoder turned even if it is set. 
	// Would replace this with lv_indev_add_event but that doesn't seem to work?
	if(idd->encoder_scroll_cb && abs(data->enc_diff)){
		idd->encoder_scroll_cb(data->enc_diff);
	}
	idd->prev_encoder_value = encoder_value;

	data->state = idd->button->debouncedValue() ? LV_INDEV_STATE_RELEASED : LV_INDEV_STATE_PRESSED;
}

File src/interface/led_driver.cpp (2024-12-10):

#include <interface/led_driver.h>

uint8_t led_state;

#define MISSING_PIN1_WORKAROUND


void setup_leds()
{
	pinMode(LED_PWM, OUTPUT);
	pinMode(LED_DATA, OUTPUT);
	pinMode(LED_SHIFT_CLOCK, OUTPUT);
	pinMode(LED_STORE_CLOCK, OUTPUT);

	#ifdef MISSING_PIN1_WORKAROUND
	pinMode(3, OUTPUT);
	#endif

	analogWrite(LED_PWM, 255 - LED_DEFAULT_BRIGHTNESS);
	write_to_shift_register(255);
}

void write_to_shift_register(uint8_t data)
{
	led_state = data;
	digitalWrite(LED_STORE_CLOCK, 0);
	shiftOut_msbFirst(LED_DATA, LED_SHIFT_CLOCK, data);

	#ifdef MISSING_PIN1_WORKAROUND
	analogWrite(3, (led_state & LED_BYPASS) * LED_DEFAULT_BRIGHTNESS);
	#endif

	digitalWrite(LED_STORE_CLOCK, 1);
	digitalWrite(LED_STORE_CLOCK, 0);
}

void led_toggle(uint8_t led)
{
	write_to_shift_register(led_state ^ led);
}

void led_set(uint8_t led, bool on = true)
{
	if(on) write_to_shift_register(led_state | led);
	else write_to_shift_register(led_state & ~led);
}

uint8_t preset_leds[] = {LED_PRESET_1, LED_PRESET_2, LED_PRESET_3, LED_PRESET_4, LED_BANK};

void led_set_preset(uint8_t preset_index)
{
	uint8_t state = led_state;
	for (size_t i = 0; i < 4; i++)
	{
		if(i <= preset_index)
		{
			state |= preset_leds[i];
		}
		else
		{
			state &= ~preset_leds[i];
		}
	}
	write_to_shift_register(state);
}

void led_set_tuner(uint8_t mask)
{
	uint8_t state = led_state;
	for (size_t i = 0; i < 5; i++)
	{
		if((mask >> i ) & 1)
		{
			state |= preset_leds[i];
		}
		else
		{
			state &= ~preset_leds[i];
		}
	}
	write_to_shift_register(state);
}

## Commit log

2024-03-11 Delay and reverb with encoders
2024-04-08 Button test
2024-05-03 Updated preamp schematic
2024-05-20 Manual wiring for dry/wet mixer
2024-07-19 Unit string, two encoder navigation
2024-07-24 Fixed color byte order
    [display.cpp]
2024-09-06 Preamp filter design
    [BOM.csv, Group Delay.csv, Input Impedance Magnitude.csv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]
2024-09-15 Tuned non-inverting preamp schematic
2024-09-15 Fixed loading active preset
    [display.cpp, input_events.cpp, main.cpp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]
2024-09-29 Kicad preamp schematic
    [mcguitarpedal.kicad_pcb, mcguitarpedal.kicad_sch, pins.xlsx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]
2024-09-30 Teensy symbol libraries
    [preamp.kicad_sch]
2024-10-06 Revised pinout
    [pins.xlsx]
2024-10-08 Schematic symbols
    [mcguitarpedal.kicad_sch, pins.xlsx, preamp.kicad_sch]
2024-10-08 4094 wiring
    [mcguitarpedal.kicad_sch, pins.xlsx]
2024-10-12 ILI9488 schematic
    [mcguitarpedal.kicad_sch, pins_variant.xlsx, preamp.kicad_sch]
2024-10-12 PCB physical layout
    [mcguitarpedal.kicad_pcb, mcguitarpedal.kicad_sch, preamp.kicad_sch]
2024-10-13 Basic PCB routing
    [mcguitarpedal.kicad_pcb, mcguitarpedal.kicad_sch, pins.xlsx]
2024-10-13 Mostly routed board
    [mcguitarpedal.kicad_pcb, mcguitarpedal.kicad_sch]
2024-10-13 Reorganized power section
    [mcguitarpedal.kicad_pcb]
2024-10-14 Encoder headers
    [mcguitarpedal.kicad_pcb, mcguitarpedal.kicad_sch]
2024-10-15 Changed to DPDT switches
    [mcguitarpedal.kicad_pcb, mcguitarpedal.kicad_sch, preamp.kicad_sch]
2024-10-16 Rearranged preamp circuit
    [mcguitarpedal.kicad_pcb, mcguitarpedal.kicad_sch]
2024-10-20 HCT595, audio shield sockets
    [mcguitarpedal.kicad_pcb, mcguitarpedal.kicad_sch, pins.xlsx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]
2024-10-20 Reorganized power traces
    [mcguitarpedal.kicad_pcb]
2024-10-21 Routing additonal power
    [mcguitarpedal.kicad_pcb, pins.xlsx, preamp.kicad_sch]
2024-10-22 Display backlight control schematic
    [mcguitarpedal.kicad_sch]
2024-10-23 Backlight control, PWR leds
    [mcguitarpedal.kicad_pcb, mcguitarpedal.kicad_sch, pins.xlsx]
2024-10-24 Final encoder and display pinout
2024-10-24 Rearranged pullups
    [mcguitarpedal.kicad_pcb, pins.xlsx, preamp.kicad_sch]
2024-10-25 Silkscreen labeling
    [mcguitarpedal.kicad_pcb, mcguitarpedal.kicad_sch, preamp.kicad_sch]
2024-10-28 Final 1.0 design
    [bom.csv, designators.csv, mcguitarpedal.kicad_pcb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]
2024-11-17 Encoder shroud mechanical design
    [encoder-shroud.step]
2024-11-18 LED test
2024-11-19 Encoder shroud V2
2024-11-19 Redesigned shroud mounting
2024-11-22 LED definitions
2024-11-23 Button decoder test
2024-11-27 Auxillary button holes
2024-11-29 Button decoder logic
2024-11-30 Preset leds
2024-12-03 Fixed initial preset number display
    [input_events.cpp]
2024-12-05 Show active effects using LEDS
2024-12-07 USB audio
    [pins.xlsx]
2024-12-08 Front plate design 4
    [encoder_shroud_4.step, led_covers.step, pins.xlsx]
2024-12-09 Front cover plate
    [encoder_shroud_4.step, front_cover.step]
2024-12-10 Bypass LED, adcHighPassFilterDisable
2024-12-14 Missing models, PCB pdf exports
    [mcguitarpedal.kicad_pcb, mcguitarpedal.kicad_sch, preamp.kicad_sch]
2025-01-02 Case sensitive includes
